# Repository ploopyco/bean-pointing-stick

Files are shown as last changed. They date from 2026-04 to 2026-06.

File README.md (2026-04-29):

# The Ploopy Bean Pointing Stick Mouse

The Ploopy Bean Pointing Stick

By some stroke of luck, you've made your way here. The Ploopy Bean. Your life will never be the same.

This repository contains all of the design and production files necessary to make a Ploopy Bean. We've also included some kick-ass documentation on how to get it made, assemble it, and program it [which you can find here](https://ploopyco.github.io/bean-pointing-stick/).

What are you waiting for? Your new life awaits.

## QMK?!

Beans bought from the [Ploopy store](https://ploopy.co/shop/bean-pointing-stick/) come with QMK preloaded. [Check out the documentation](https://ploopyco.github.io/bean-pointing-stick/) for instructions on how to load new firmware onto your device. (It's super easy!)

The firmware file that ships with all Beans is included in this repository as well, as `firmwares/bean.uf2`.

In case you are new to the world of QMK, it is an open-source firmware for computer input peripherals. You can find the source code for all of our firmwares in [QMK's Github repository](https://github.com/qmk/qmk_firmware/tree/master/keyboards/ploopyco).

Note that you may have to look for specific development branches in order to find the source for all of our firmwares, as we frequently have pending pull requests.

## Under what license is this released?

As per QMK's licensing requirements, the firmware for the Ploopy Bean Pointing Stick is released under GPLv3. Hardware design files, including electronics and mechanical files, are released under OHL CERN v2-S. Check the respective directories for full license text.

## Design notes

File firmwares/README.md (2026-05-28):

The firmware that ships on all Beans is `bean.uf2`.

## MacOS scrolling issues

Certain operating systems, like MacOS, don't play well with the high-res scrolling implementation. For more details, see: https://github.com/qmk/qmk_firmware/issues/17585#issuecomment-2325248167

This issue causes the drag scroll function to go much too fast on MacOS. The current fix is to use the `bean_no_high_res_scroll.uf2` firmware, which reduces scrolling to a usable speed.

Flashing the new firmware is easy; just hold down the bottom-left button while plugging the Bean in. Your computer should recognize a USB mass storage device was just plugged in. After that, copy and paste the firmware onto the device, and you're done.

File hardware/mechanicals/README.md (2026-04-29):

## Only one file? Where are the parts?

The STEP/STL files contain all of the plastic parts in one file. Doing it this way preserves the assembly information, showing how the parts are supposed to fit together, as well as the expected clearances between parts. It also bundles all of the parts for a given revision together, so there's no accidental mixing of parts from different revisions.

## How do I print this?

You'll need to split the parts in the file up before you can print them. Most slicers can do this; if you have a compatible printer we recommend PrusaSlic3r, since that's the one we use in-house and have checked.

Note that submitting this file to some 3rd party print services will cause confusion, as they are expecting one body instead of many. To do this, you can use PrusaSlic3r to split the parts and then export each separately as an STL.

## Why don't you include a .gcode file?

For your safety. Uploading a .gcode file onto a printer can be extremely hazardous if that .gcode file wasn't specifically generated for that printer. We don't want to come anywhere near that sort of scenario, so we are not going to upload a .gcode file.

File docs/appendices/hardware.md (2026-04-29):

# Appendix C: Hardware

## Buying hardware from us

Getting all of the hardware on your own can be tricky because the parts you select may not fit perfectly. [That's why we sell fully-assembled Beans](https://ploopy.co/product-category/bean/). Here's why that's great for you:

- Everything is guaranteed to fit together perfectly
- Everything is guaranteed to work as intended
- You'll end up saving money - probably quite a bit of money - by not spending on extra parts

Your call. You'll sort it out.

## Getting your own hardware

This guide was a bit light on detail in the other sections, and that's because the hardware has to conform to many specifications. They'll all be listed here.

First, a complete list of all the hardware you'll need:

- \#2 3/8" screw
- 6mm diameter x 2mm thick magnet
- 4x friction pads

We'll be going over all of them in detail. There will be mentions of *critical specifications*; if you're going to be sourcing your own parts, **you must get parts that conform to the critical specifications**. If you go off-menu, the parts will not fit the way that we intended when we designed the Bean. That might mean that your Bean **doesn't work**.

Let's get cracking.

### Screws

Here are the critical specifications:

- \#2
- 3/8" length

### Magnets

Here are the critical specifications:

- 6mm diameter
- 2mm thickness

### Friction pads

Here are the critical specifications:

- Any size
- Non-slip

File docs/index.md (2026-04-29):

# Home

So, you want to build a Ploopy Bean, eh? Or, maybe you want to replace some broken parts. Maybe you want to reprogram it. Or maybe you just want to know how it all works. No matter the motivation, this is the place to learn.

**Sourced the parts and itching to get it built?** --> Get started by going to the [assembly instructions](assembly-instructions.md).

**Looking to purchase your own Bean?** --> [Check out the Ploopy store](https://ploopy.co/product-category/bean).

**Building a Ploopy Bean from scratch?** --> Get started by going to [Appendix A: Printed circuit boards](appendices/pcbs.md).

---

*Copyright (C) 2026 Ploopy Corporation. Permission is granted to copy, distribute and/or modify this document under the terms of the GNU Free Documentation License, Version 1.3 or any later version published by the Free Software Foundation; with no Invariant Sections, no Front-Cover Texts, and no Back-Cover Texts. A copy of the license is included in the section entitled "GNU Free Documentation License".*

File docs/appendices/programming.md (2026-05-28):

# Appendix D: QMK Firmware Programming

## Working with QMK

Ploopy devices are fairly easy to program and reprogram, thanks to the excellent work by all of the developers and maintainers of the [QMK firmware suite](https://github.com/qmk/qmk_firmware).

## Before you begin

If you have never used QMK before, go through [all of the steps in the QMK guide to set up your environment](https://docs.qmk.fm/#/newbs_getting_started).

QMK was built for keyboards, so you'll see lots of references to code that looks like the following:

`-kb <keyboard>`

Whenever you see that, use the following syntax:

`-kb ploopyco/bean`

and you'll be fine.

## Building the Ploopy device firmware

Using QMK MSYS or your compilation toolchain of choice, compile the firmware with the following command:

`qmk compile -kb ploopyco/bean/rev1_001 -km default`

For more details on building QMK firmware in general, see the [QMK firmware guide](https://docs.qmk.fm/#/newbs_building_firmware).

## Putting the Ploopy device into bootloader mode

Under normal circumstances, the device can be put into bootloader mode with a special startup procedure.

1. Identify the "bootloader" button on the device's keymap. [The default keymap is available here](keymap.md).
2. Unplug the device.
3. Hold down the "bootloader" button.
4. Plug in the device.
5. The computer should recognise that a mass storage device was just plugged in. Once this is done, you should be able to drag and drop files onto the Ploopy device, as if the board was a USB drive.

And that's it. While plugged in this way, the Ploopy device will accept new firmware.

If you want to upload a new firmware file (a ".uf2" file, like "ploopy_aplus_v42069" or something), just drag it into the folder, and it'll automatically install on the Ploopy device and restart itself.

## Putting the Ploopy device into bootloader mode if the device is bricked

If the device cannot be put into bootloader mode using the above procedure, there is another procedure that can be used to force the device into bootloader mode. However, it involves opening the device and is more involved.

1. Unplug it from your computer.
2. Open it by removing the screws in the Base and removing the Top.
3. Look for a pair of vias (gold-plated holes) on the board. Here's a photo for reference:

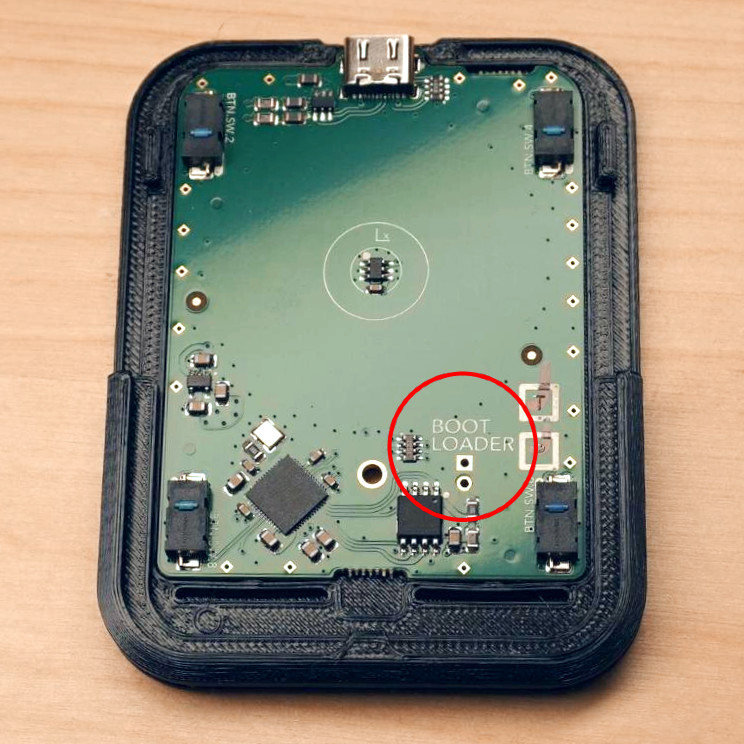
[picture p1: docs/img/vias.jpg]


4. Get a paper clip (non-insulated, i.e. no plastic covering it) or a pair of tweezers, or some wire. Whatever you've got on hand that's metal.
5. Stick the paper clip or tweezers into the holes. You're trying to form an electrical connection between the two holes.
6. While you've got the two vias connected with your metal bridge, plug the Ploopy device into your computer.
7. The computer should recognise that a mass storage device was just plugged in. Once this is done, you should be able to drag and drop files onto the Ploopy device, as if the board was a USB drive. Feel free to remove the tweezers or paperclip at this point.

And that's it. While plugged in this way, the Ploopy device will accept new firmware.

If you want to upload a new firmware file (a ".uf2" file, like "ploopy_bean_v42069" or something), just drag it into the folder, and it'll automatically install on the Ploopy device and restart itself.

Whenever you want to put new firmware onto the Ploopy device, go through these steps again.

**TIP**: If your firmware is in some kind of strange state and uploading new firmware isn't fixing it, try uploading [a flash nuke](https://learn.adafruit.com/getting-started-with-raspberry-pi-pico-circuitpython/circuitpython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) to the bean before flashing the new firmware. It wipes the memory of the bean completely clean, which can help clear a few types of errors.

## And that's it!

Happy customizing!

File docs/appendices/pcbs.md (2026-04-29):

# Appendix A: Printed circuit boards

## Buying boards from us
Getting the Ploopy boards made can be complex, and expensive, especially if you only need one set. [That's why we sell fully-assembled Beans](https://ploopy.co/product-category/Bean/). Here's why that's great for you:

- You get a PCB with all components soldered
- The firmware is already programmed on the microcontroller, so you won't have to program it
- It'll cost a hell of a lot less than if you do a production run of PCBs just for yourself
- You won't have to order components and wait while they come in
- We guarantee that it works

Just something to consider. You're smart. You'll figure it out.

## Making your own boards

Want to make your own Ploopy Bean boards? Great! Less work for us. Seriously, though, only choose this option if you know what you're doing. You don't want to embarrass yourself, do you?

### Step 1: Order the PCBs from a PCB production company

Here are the most important configurations you'll need to communicate to the company:

- 4 layers
- FR-4, TG 150-160 (basically, whatever the cheapest option is)
- 1.6mm thickness
- 6/6mil track/spacing distance
- 0.3mm minimum hole size
- ENIG surface finish, but you can go with HASL if you don't care about lead poisoning
- 1oz copper thickness for both outer and inner layers
- Choose whatever colours you want for solder mask and silkscreen; we like green solder mask and white silkscreen

If something is missing from here, it's not really important.

At some point, you'll have to upload design files to the production company. Use the [electronics source files](https://github.com/ploopyco/bean-pointing-stick/tree/main/hardware/electronics) to generate manufacturing files (you'll have to convert them from their native Altium format if you're using some other platform). That should contain everything you need to get the boards made. If the production company rejects this package, however, you'll need to address the issue yourself.

### Step 2: Order the electronics components

All of the components are described in the schematics of the PCBs. Ordering the components is left as an exercise for the reader.

A complete list of all of the components can be found in the electrical design files.

### Step 3: Get the necessary tools

- PCB
- All of the electronics components
- A hot air rework tool
- Solder paste
- A printout of the schematics

### Step 4: Solder the components to the boards

Once you've got the PCBs and all of the components, print out the schematics. Use the schematics to match the reference designators on the PCBs to the reference designators on the schematics, and then get to soldering.

If you've never soldered surface mount components before, or want a refresher on how to solder, we recommend [this video on using an iron to solder surface mount components](https://www.youtube.com/watch?v=3NN7UGWYmBY), and [this video on using a hot-air soldering station](https://www.youtube.com/watch?v=c_Qt5CtUlqY).

### Step 5: All done!

Congrats, you finished assembling the electronics! Pat yourself on the back.

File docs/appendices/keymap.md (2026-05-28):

# Appendix E: Default Keymap

The default keymap for the Bean is as follows.

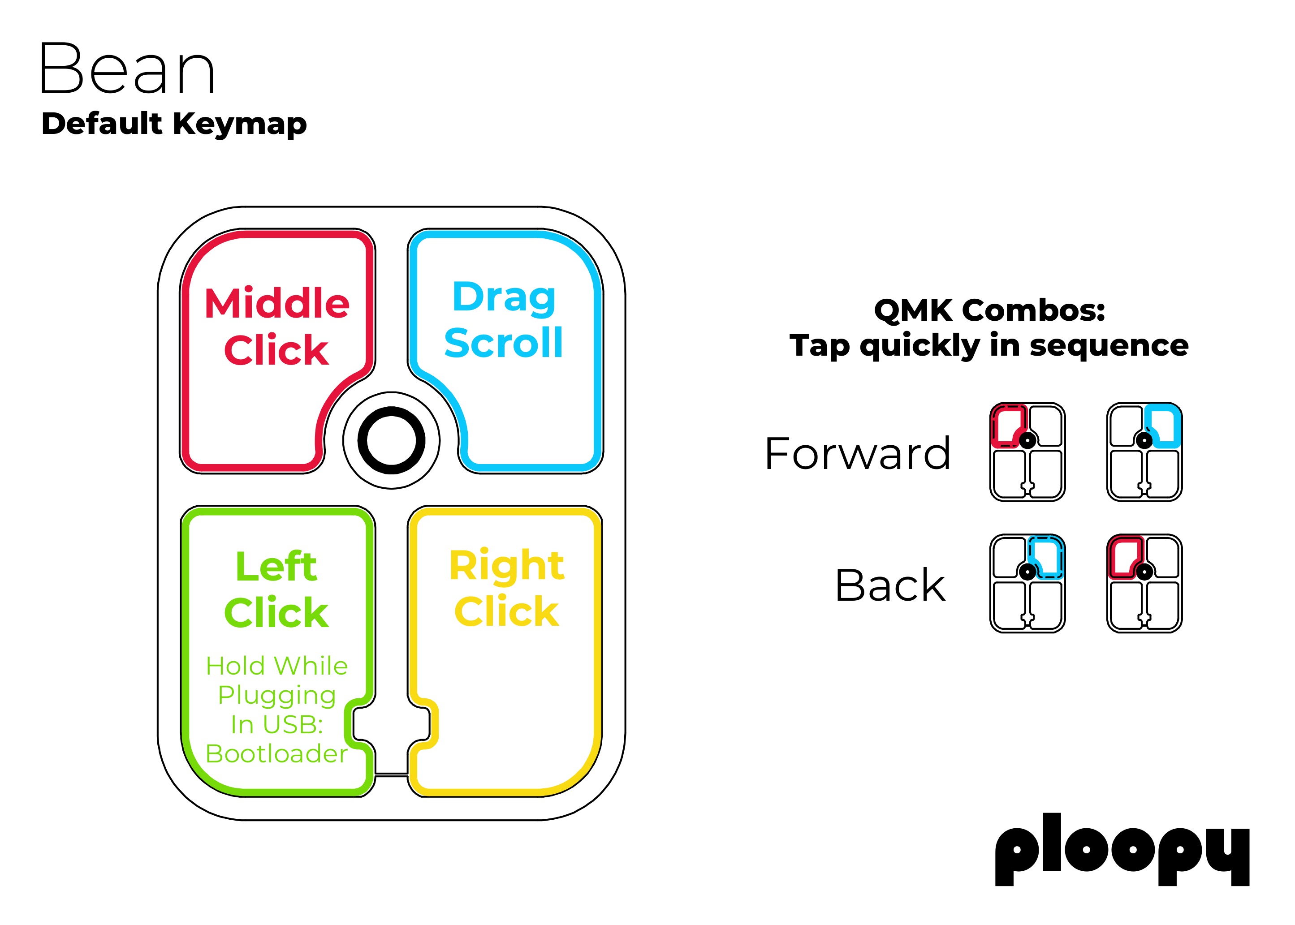
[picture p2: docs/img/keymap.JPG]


All of these functions can be customized using [VIA, a free open-source webapp](https://usevia.app).

Note that your browser needs to support WebHID in order to use VIA.

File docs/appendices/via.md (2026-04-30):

# Appendix F: Using VIA

The Bean's can be customized using a web application called "VIA". Currently, a bit of additional work is necessary to get VIA to work, but it should only take about thirty seconds.

Begin by copying and pasting the following into a text file, saving it as *bean.json*:

    {
      "name": "Ploopy Bean Pointing Stick",
      "vendorId": "0x5043",
      "productId": "0x81DC",
      "matrix": {
        "rows": 1,
        "cols": 4
      },
      "customKeycodes": [
        {
          "name": "DPI Config",
          "title": "DPI Config",
          "shortName": "DPI"
        },
        {
          "name": "Drag Scroll",
          "title": "Drag Scroll",
          "shortName": "DragScl"
        }
      ],
      "layouts": {
        "keymap": [
          [
            {
              "w": 2,
              "h": 2
            },
            "0,1",
            {
              "x": 0.25,
              "w": 2,
              "h": 2
            },
            "0,2"
          ],
          [
            {
              "y": 1.25,
              "w": 2,
              "h": 2
            },
            "0,0",
            {
              "x": 0.25,
              "w": 2,
              "h": 2
            },
            "0,3"
          ]
        ]
      }
    }

- Next, navigate to [the VIA web app](https://usevia.app), using **Microsoft Edge, Chrome, or Opera**. Any other browser that supports WebHID will work, too.
- Look at the top toolbar of the web application, and click the tab called *DESIGN*.
- Uncheck *Use V2 definitions (deprecated)*.
- Click *Load* and upload the *bean.json* file that you saved on your computer.
- Plug in the Bean if it wasn't plugged in already.
- Look at the top toolbar of the web application, and click the tab called *CONFIGURE*.
- Click *Authorize Device*. A modal window should pop up, and you should see the *Ploopy Bean* as an option to connect. Do so now.

You should now see a representation of the buttons of the Bean in the web app. You are now free to modify the button's functionality.

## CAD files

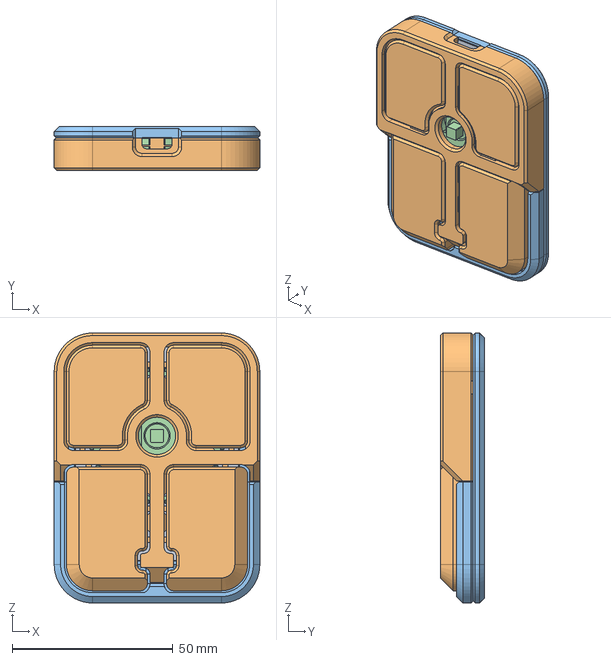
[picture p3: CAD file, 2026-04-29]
hardware/mechanicals/Bean-RevO-NoLogo.STEP
64.0 x 13.8 x 84.0 mm

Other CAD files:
hardware/mechanicals/Bean-RevO-NoLogo.STL

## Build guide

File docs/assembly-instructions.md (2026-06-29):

<style>
  .tooltip {
    padding: 15px;
    border-radius: 5px;
    margin-bottom: 10px;
    display: flex;
    align-items: center;
  }

  .tooltip .icon {
    font-size: 1rem;
    margin-right: 10px;
  }

  .tip {
    background-color: #fcf003;
    color: #333;
  }

  .warning {
    background-color: #ffb3b3;
    color: #333;
  }

  .info {
    background-color: #cce5ff;
    color: #004085;
  }

  .info a {
    color: #004085;
    font-weight: bold;
    text-decoration: underline;
  }
</style>

## Step 1: Prepare necessary tools

- A #1 Phillips head screwdriver

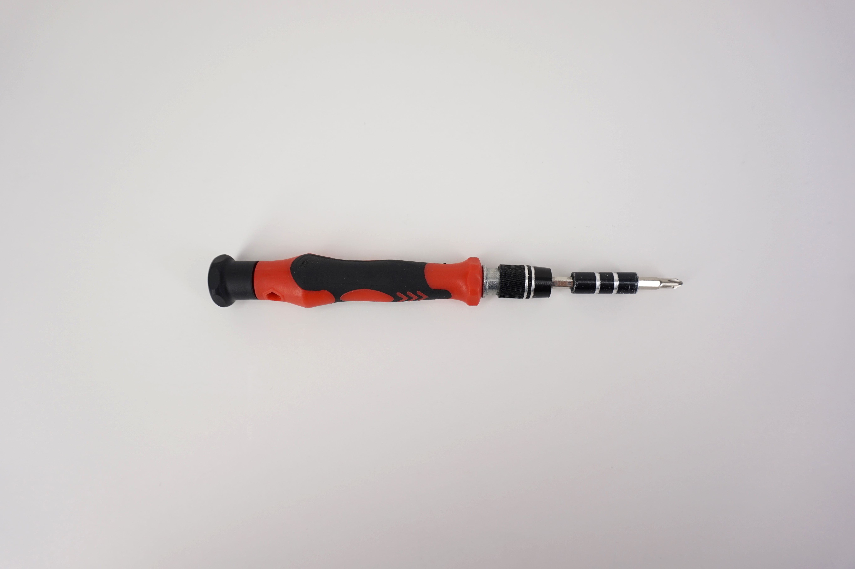
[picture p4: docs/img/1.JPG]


## Step 2: Place PCB into Base

<div class="tooltip tip">
  <span class="icon">💡</span>
  <span><strong>Tip:</strong> The PCB may require a bit of force to get in.</span>
</div>

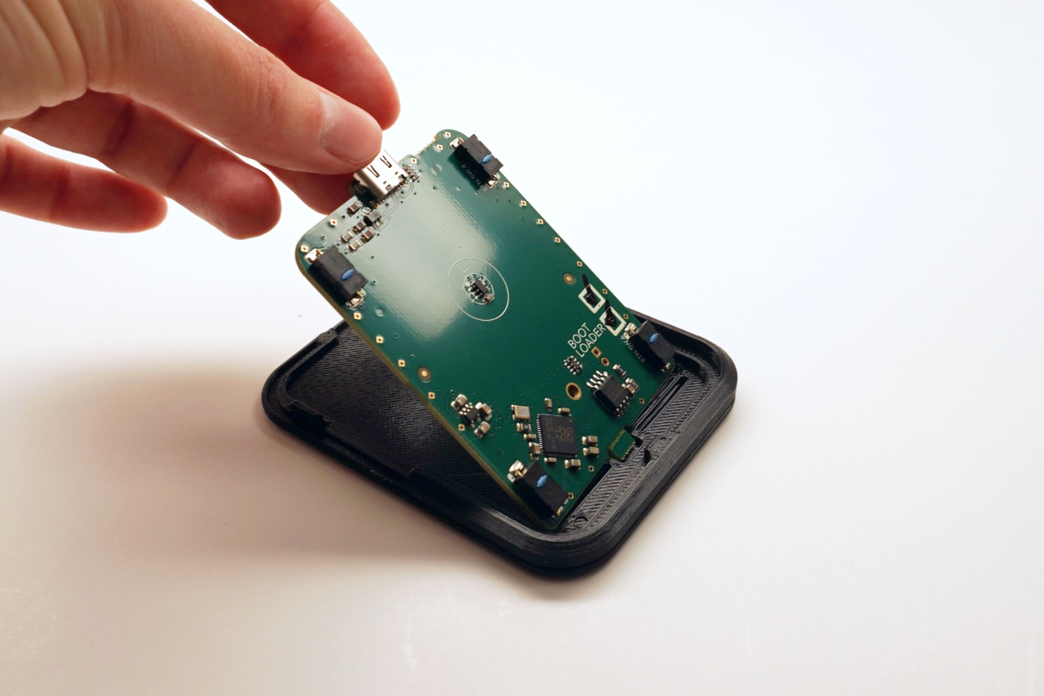
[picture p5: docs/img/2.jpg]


## Step 3: Insert Magnet into Spring

<div class="tooltip tip">
  <span class="icon">💡</span>
  <span><strong>Tip:</strong> The magnet must be inserted with the <b>north</b> side facing <b>upwards</b>. Use a compass to determine the orientation of the magnet.</span>
</div>

- The magnet requires a bit of force to fully insert.
- Once inserted, the Magnet will be very difficult to remove.

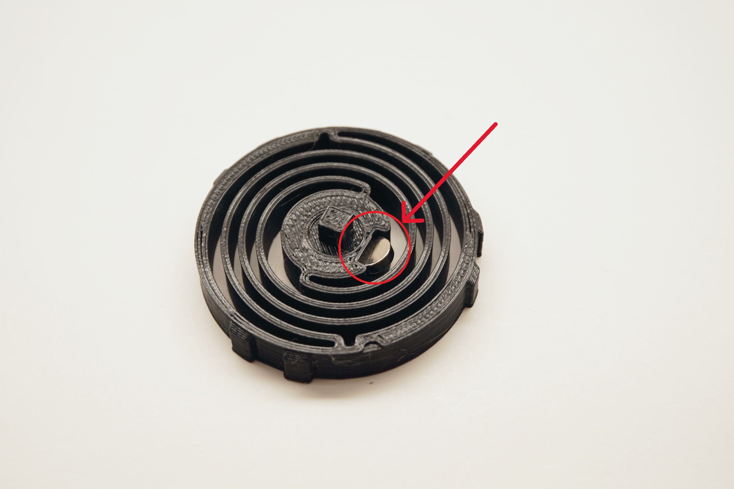
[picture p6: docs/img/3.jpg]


## Step 4: Place Friction Nub onto Spring

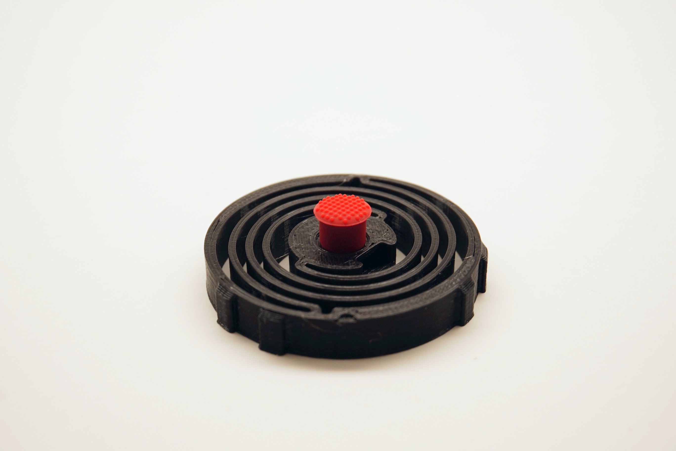
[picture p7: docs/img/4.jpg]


## Step 5: Place Spring into Top

<div class="tooltip tip">
  <span class="icon">💡</span>
  <span><strong>Tip:</strong> The Spring must be oriented correctly in order to properly insert. See the photo for details.</span>
</div>

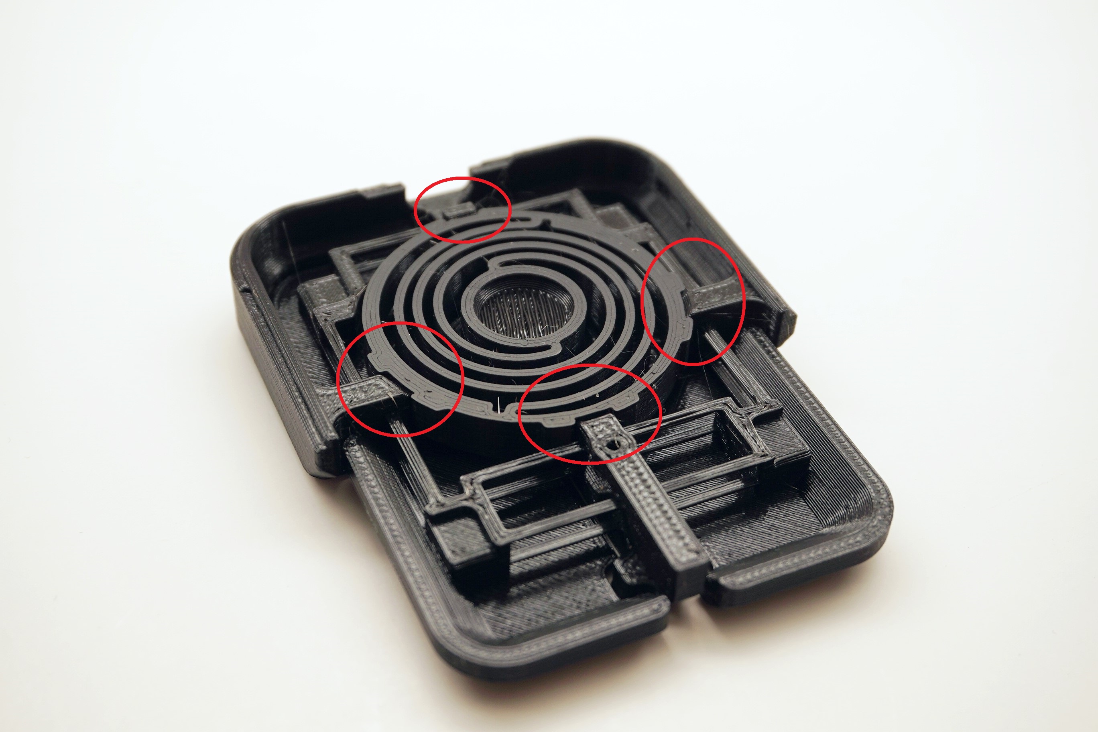
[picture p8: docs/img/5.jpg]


## Step 6: Place Top onto Base

<div class="tooltip tip">
  <span class="icon">💡</span>
  <span><strong>Tip:</strong> The Top should snap into place on the Base.</span>
</div>

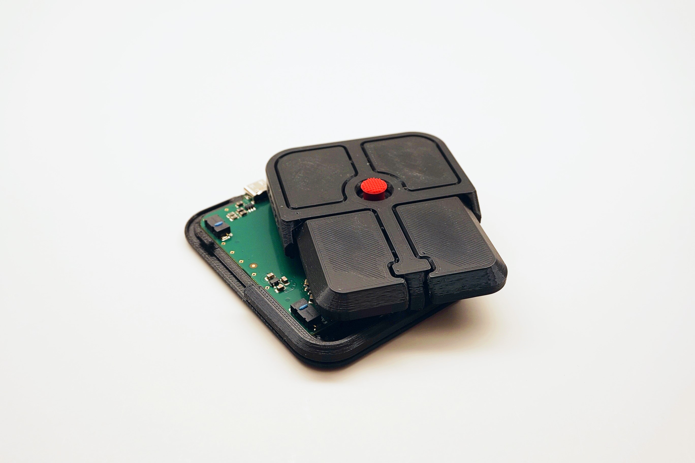
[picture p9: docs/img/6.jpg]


## Step 7: Screw Top to Base

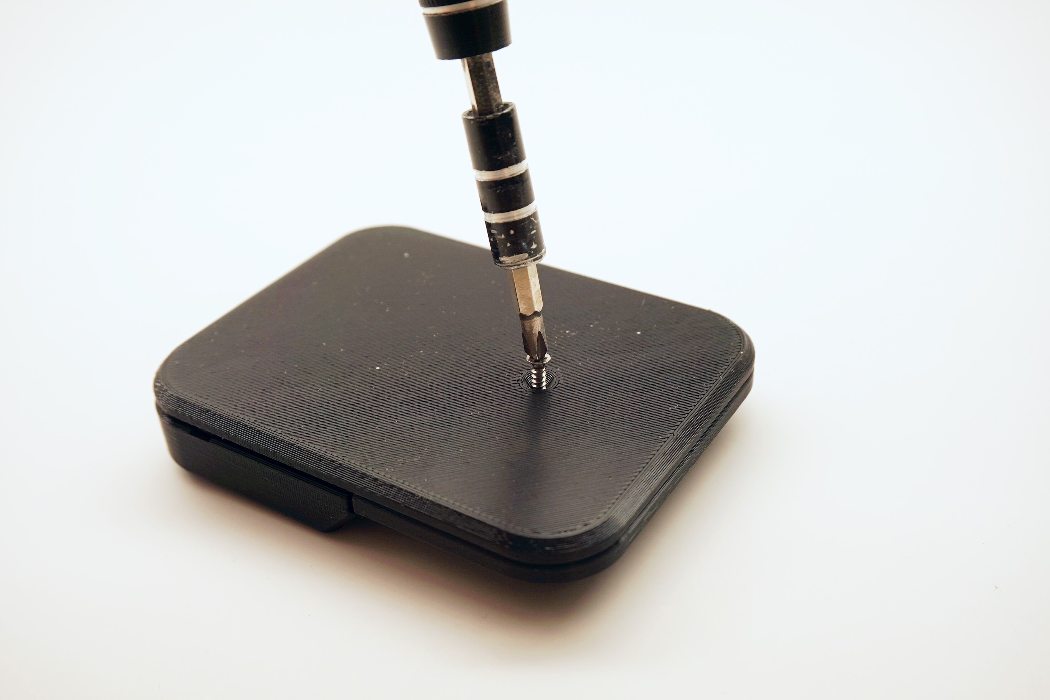
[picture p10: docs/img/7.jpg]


## Step 8: Place Friction Pads on Base

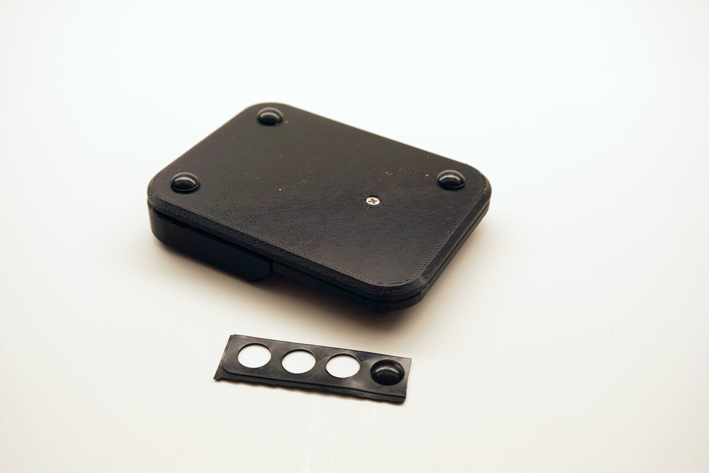
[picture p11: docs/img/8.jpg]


## Step 9: All done!

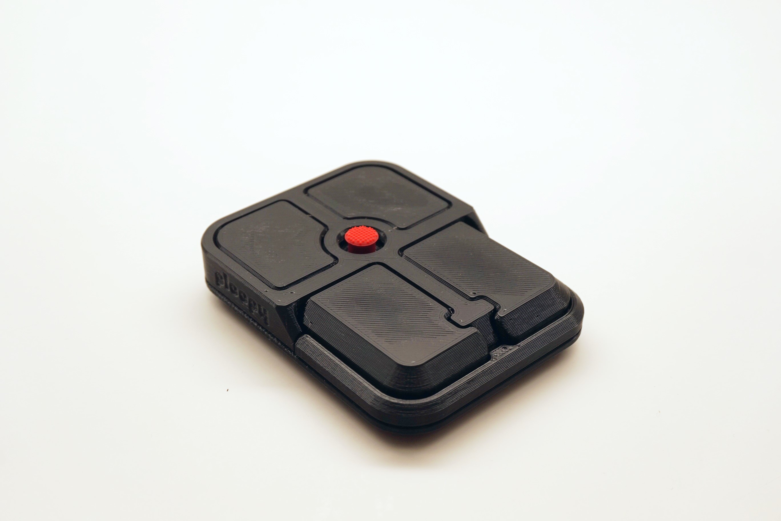
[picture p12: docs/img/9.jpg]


## Post Build Steps:

### Verify the device is working correctly

- Plug the Bean into the computer using a USB-C cable
- Move the nub around, it should move the cursor
- Press each of the buttons to verify their function

<div class="tooltip info">
  <span class="icon">ℹ️</span>
  <span><strong>Info:</strong> The default keymap for the Bean is <a href="../appendices/keymap/">here</a>.</span>
</div>

### Check out Post Build FAQ
- [Post Build FAQ](https://help.ploopy.co/?docs=where-can-i-find-mods-for-my-ploopy-device)
- Contains various information about things you can do after initial assembly!

<div class="tooltip info">
  <span class="icon">ℹ️</span>
  <span><strong>Info:</strong> If the device is not working, consult our <a href="https://help.ploopy.co/checklist-v2/">troubleshooting guide</a> for further steps.
</div>

<!--
<div class="tooltip tip">
  <span class="icon">💡</span>
  <span><strong>Tip:</strong> Here's an interesting piece of info!</span>
</div>

<div class="tooltip warning">
  <span class="icon">🚨</span>
  <span><strong>Warning:</strong> Here's a warning!</span>
</div>

<div class="tooltip info">
  <span class="icon">ℹ️</span>
  <span><strong>Info:</strong> Here's some cool stuff!</span>
</div>
-->

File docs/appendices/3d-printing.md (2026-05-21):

# Appendix B: 3D printed parts

## Buying 3D-printed parts from us
Not everyone has access to a 3D-printer. [That's why we sell fully-assembled Beans](https://ploopy.co/product-category/bean/). Here's why that's great for you:

- You get all of the 3D-printed parts, guaranteed free of manufacturing defects
- You won't waste time spending hours tweaking settings
- We guarantee it will fit together *perfectly*

Consider it. You're a smartie. You'll get there.

## Printing your own parts

So, you have a printer and want to print your own parts? Great! We don't have specific instructions, since every printer setup is different. All of the STLs are available, and if you need to make tweaks, you can alter the design files.

Here are the settings we use when we print parts. **Note that these settings have only been tested on the Prusa i3 MK2.5S and MK3S.** If you have another printer, you may need to tweak these settings.

- PLA. The geometry of many of the parts is quite complex; trying to use other materials may not result in success.
- 0.20mm layer height. You can go finer than this if you want, but we haven't tested that. Going coarser is not going to work; first, it's going to feel rough on your hand, and second, it won't accurately capture the necessary detail.
- No support material is necessary. If your slicer is showing support material, you didn't orient the parts correctly.
- Orient the pieces so that flat sides are on the build plate.
- We like gyroid for infill pattern, but anything is probably good. Cubic, rectilinear, whatever.
- We use 0.4mm nozzles. We haven't tested other nozzle sizes.

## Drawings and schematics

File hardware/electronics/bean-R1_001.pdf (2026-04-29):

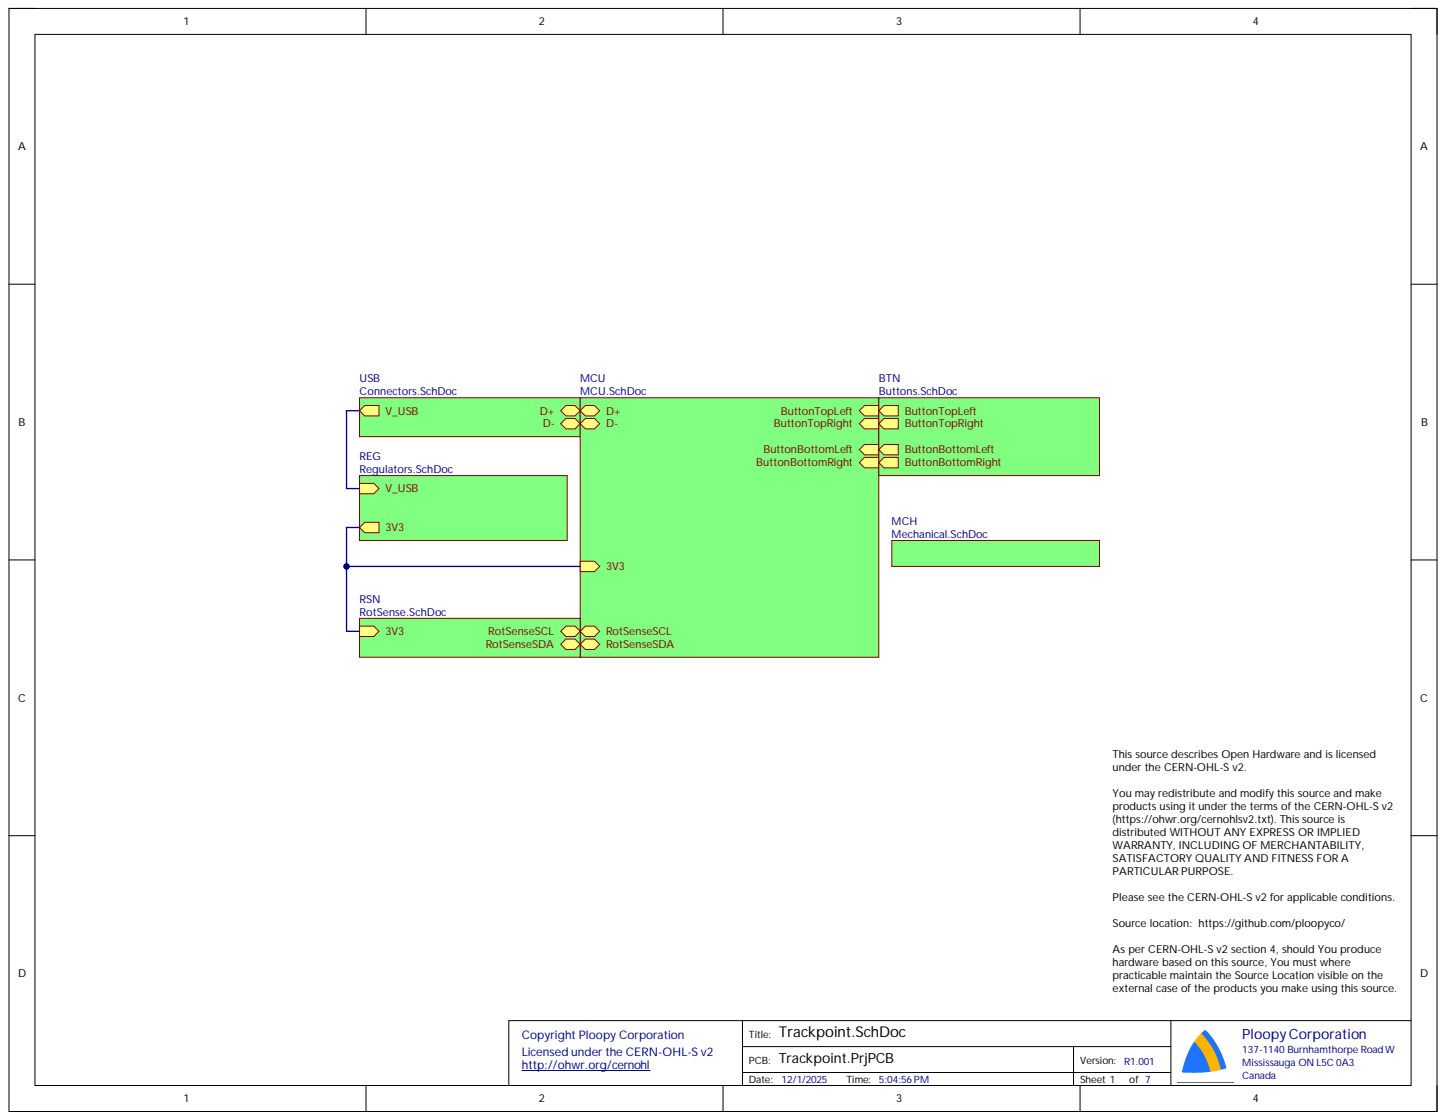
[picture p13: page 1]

This source describes Open Hardware and is licensed
under the CERN-OHL-S v2.

You may redistribute and modify this source and make
products using it under the terms of the CERN-OHL-S v2
(https://ohwr.org/cernohlsv2.txt). This source is
distributed WITHOUT ANY EXPRESS OR IMPLIED
WARRANTY, INCLUDING OF MERCHANTABILITY,
SATISFACTORY QUALITY AND FITNESS FOR A
PARTICULAR PURPOSE.

Please see the CERN-OHL-S v2 for applicable conditions.

Source location: https://github.com/ploopyco/

As per CERN-OHL-S v2 section 4, should You produce
hardware based on this source, You must where
practicable maintain the Source Location visible on the
external case of the products you make using this source.

Copyright Ploopy Corporation
Licensed under the CERN-OHL-S v2
http://ohwr.org/cernohl

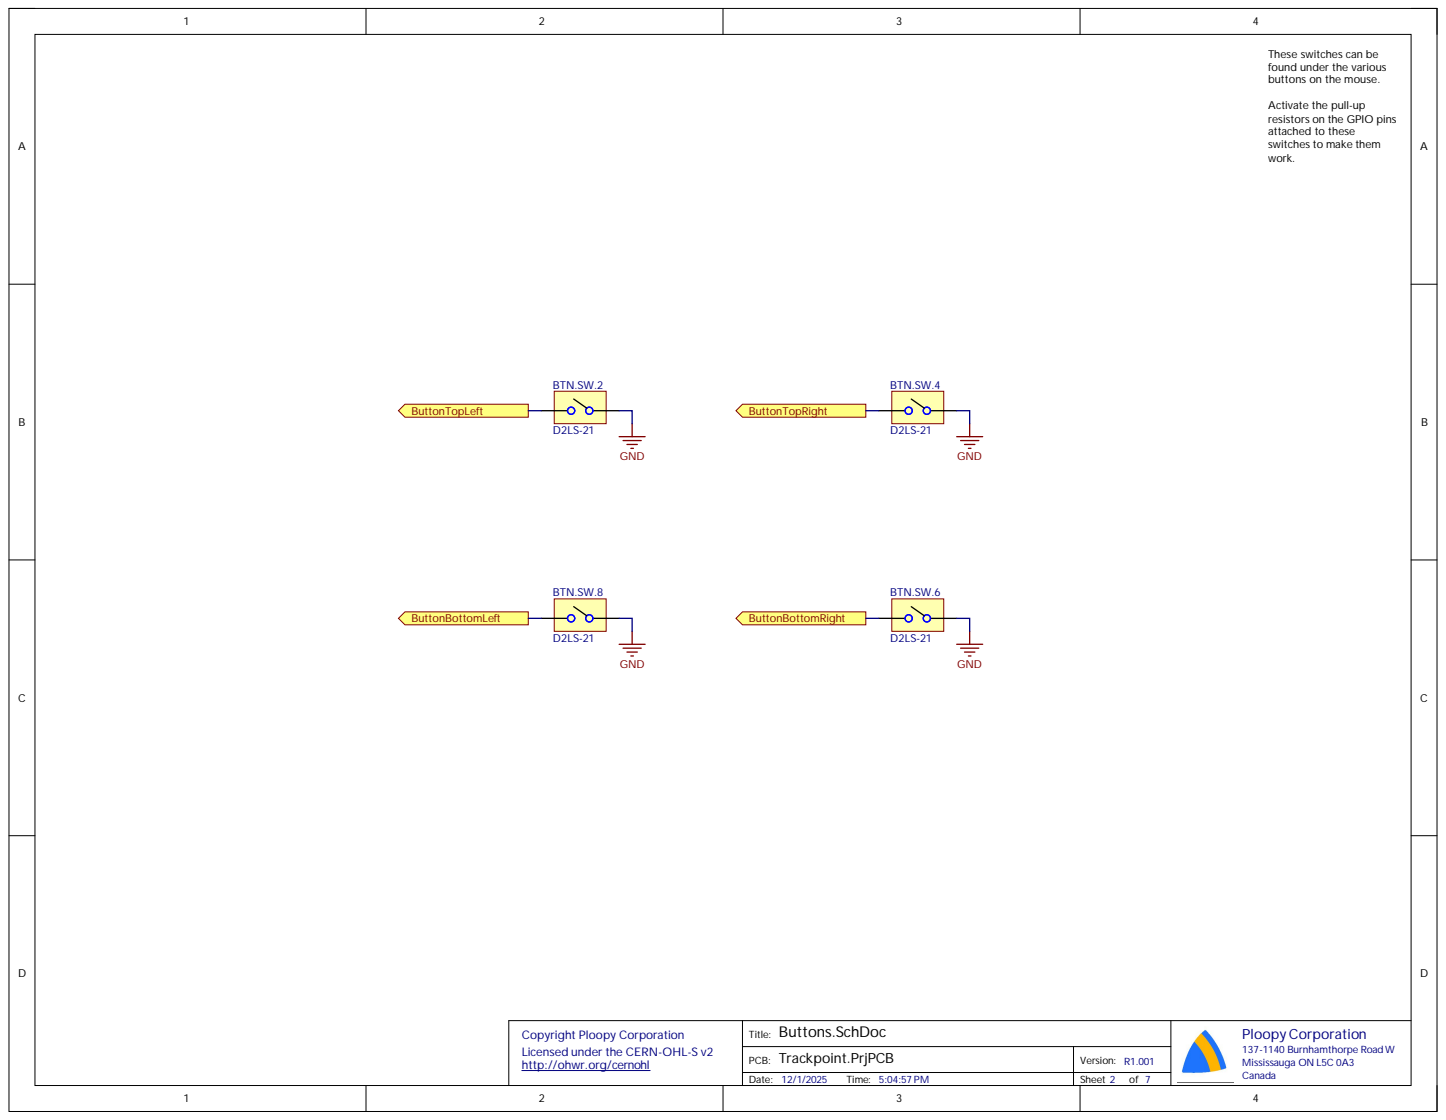
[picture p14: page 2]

These switches can be
found under the various
buttons on the mouse.

Activate the pull-up
resistors on the GPIO pins
attached to these
switches to make them
work.

Copyright Ploopy Corporation
Licensed under the CERN-OHL-S v2
http://ohwr.org/cernohl

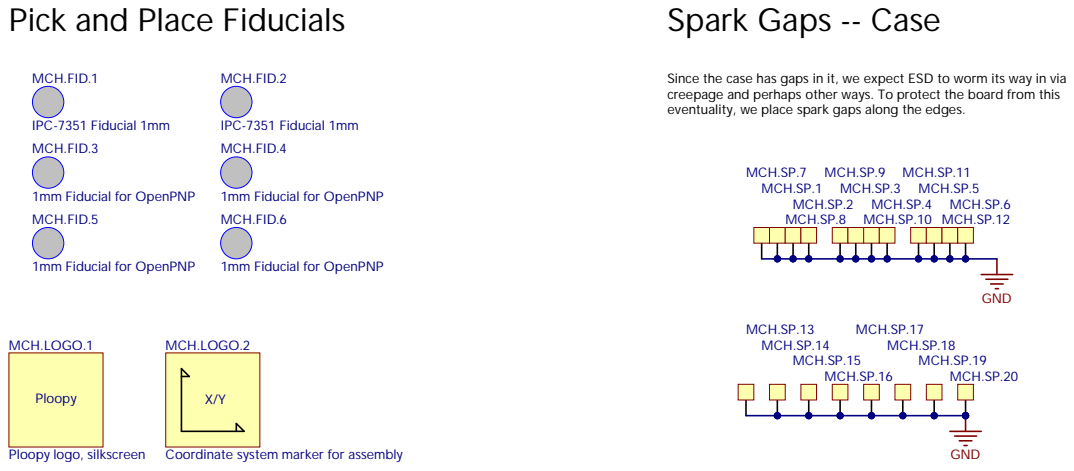
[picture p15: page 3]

Pick and Place Fiducials

Spark Gaps -- Case MCH.SP.7 MCH.SP.1 MCH.SP.8 MCH.SP.2 MCH.SP.9 MCH.SP.3 MCH.SP.10 MCH.SP.4 MCH.SP.1

Since the case has gap
creepage and perhap
eventuality, we place spark gap

s other ways. To protect the board from this

pect ESD to worm its way in via

Coordinate system marker for assem

Cop
Licensed under the CE
http

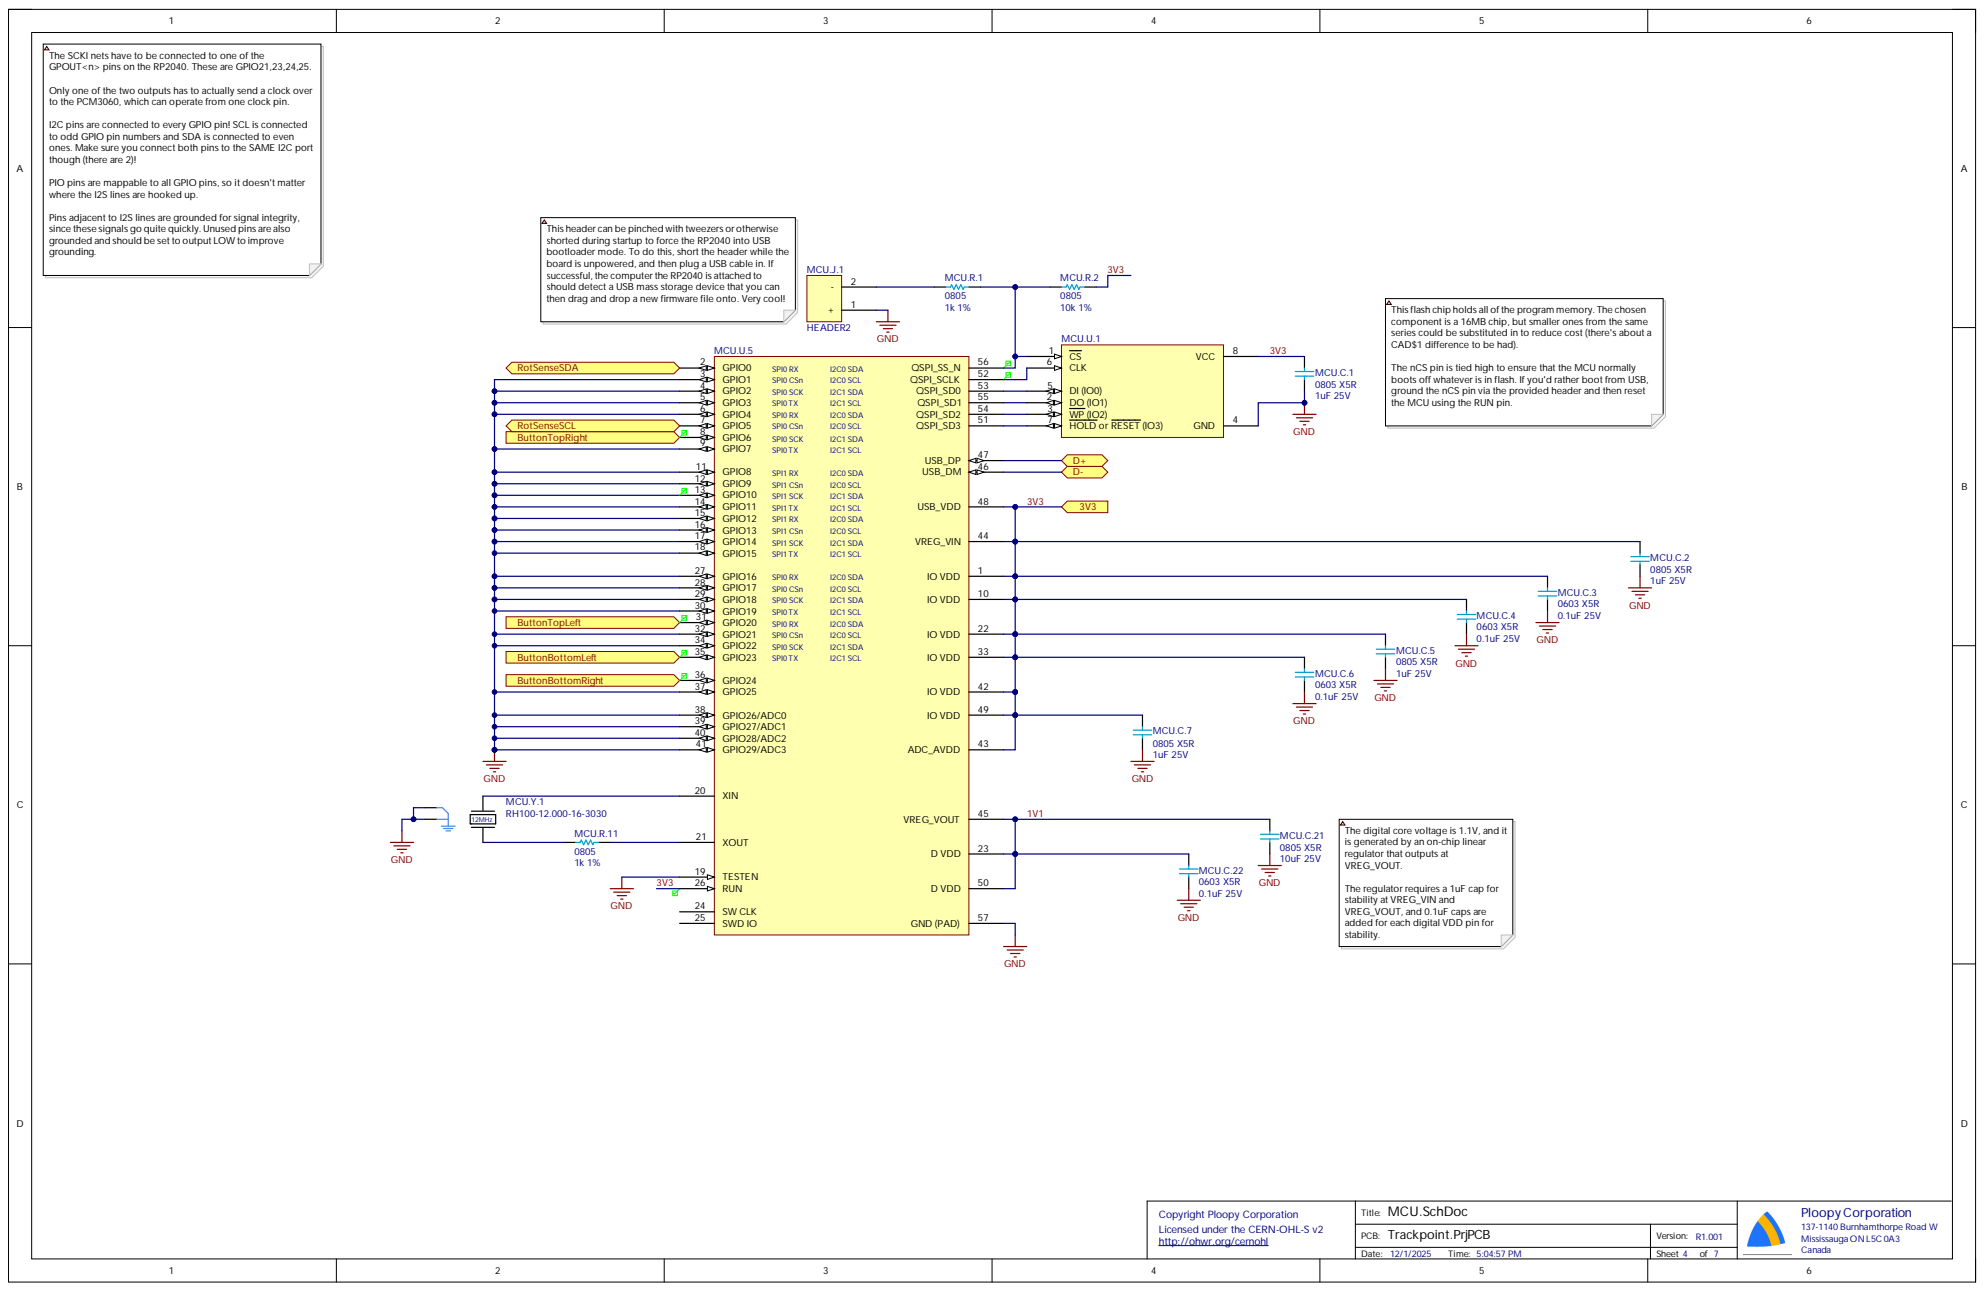
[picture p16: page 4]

The SCKI nets have

R o tSenseSC L 7 ButtonT o p R i g ht | | 7

Cop y rig h t Ploop y Corpora tion Lice nsed u n d e r th e CE R N -OH L -S v 2 h ttp : //ohwr .org /ce rnoh l | T i tl e: MC U.Sc h Doc | Plo opy C o rpo ra ti o n 1 37-1 1 40 B u rn h a m thorp e Roa d W M i ssi ssa u g a O N L 5C 0A 3 C a n ad a

PC B : Trackpoin t.P rj PC B | Ve rsion : R 1 . 001

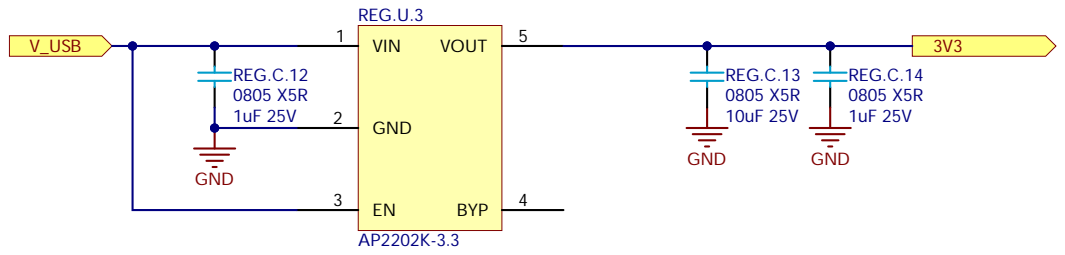
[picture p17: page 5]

Copyright Ploopy Corporation
Licensed under the CERN-OHL-S v2
http://ohwr.org/cernohl

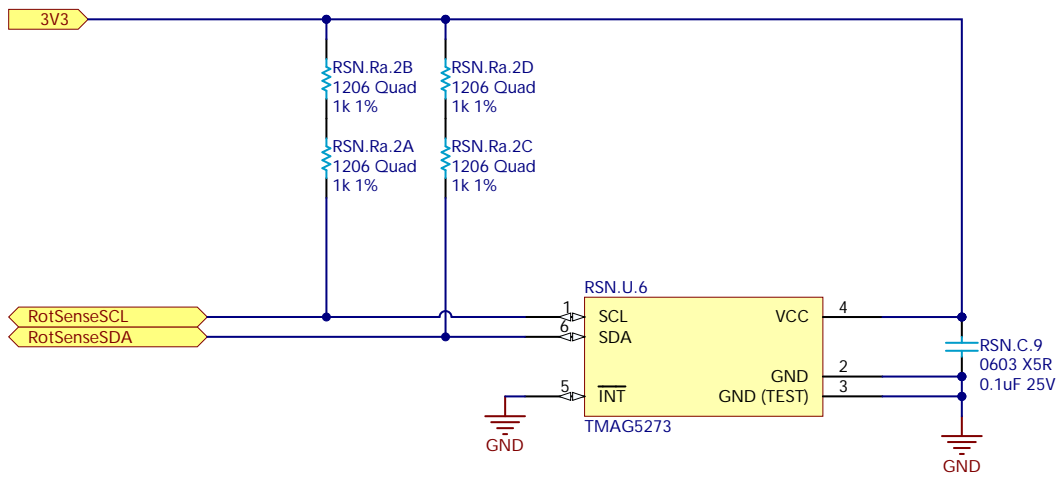
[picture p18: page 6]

Cop
Licensed under the CE
http

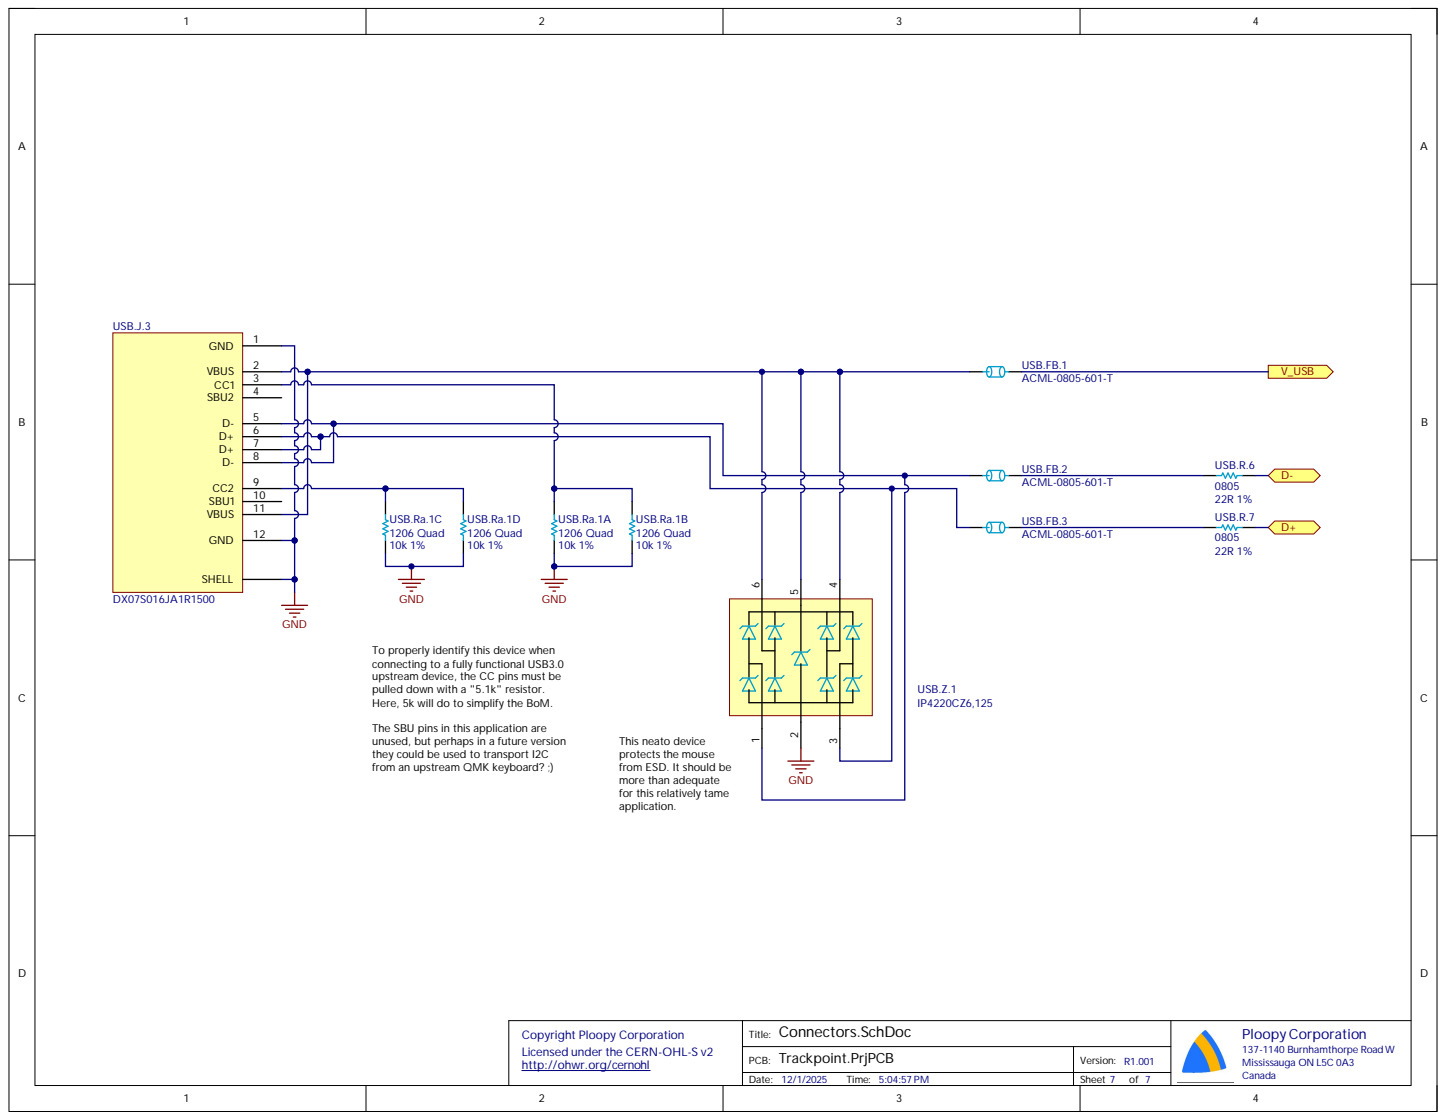
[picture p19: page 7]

To properly identify this device when
connecting to a fully functional USB3.0
pulled down with a "5.1k" resistor.
Here, 5k will do to sim

The SB
unused, but perhap
they could be used to transport I2C
from an up

U pins in this ap

This neato device protects the mouse

from ESD. It should be more than adequate

for this relatively tame

Cop
Licensed under the CE
http

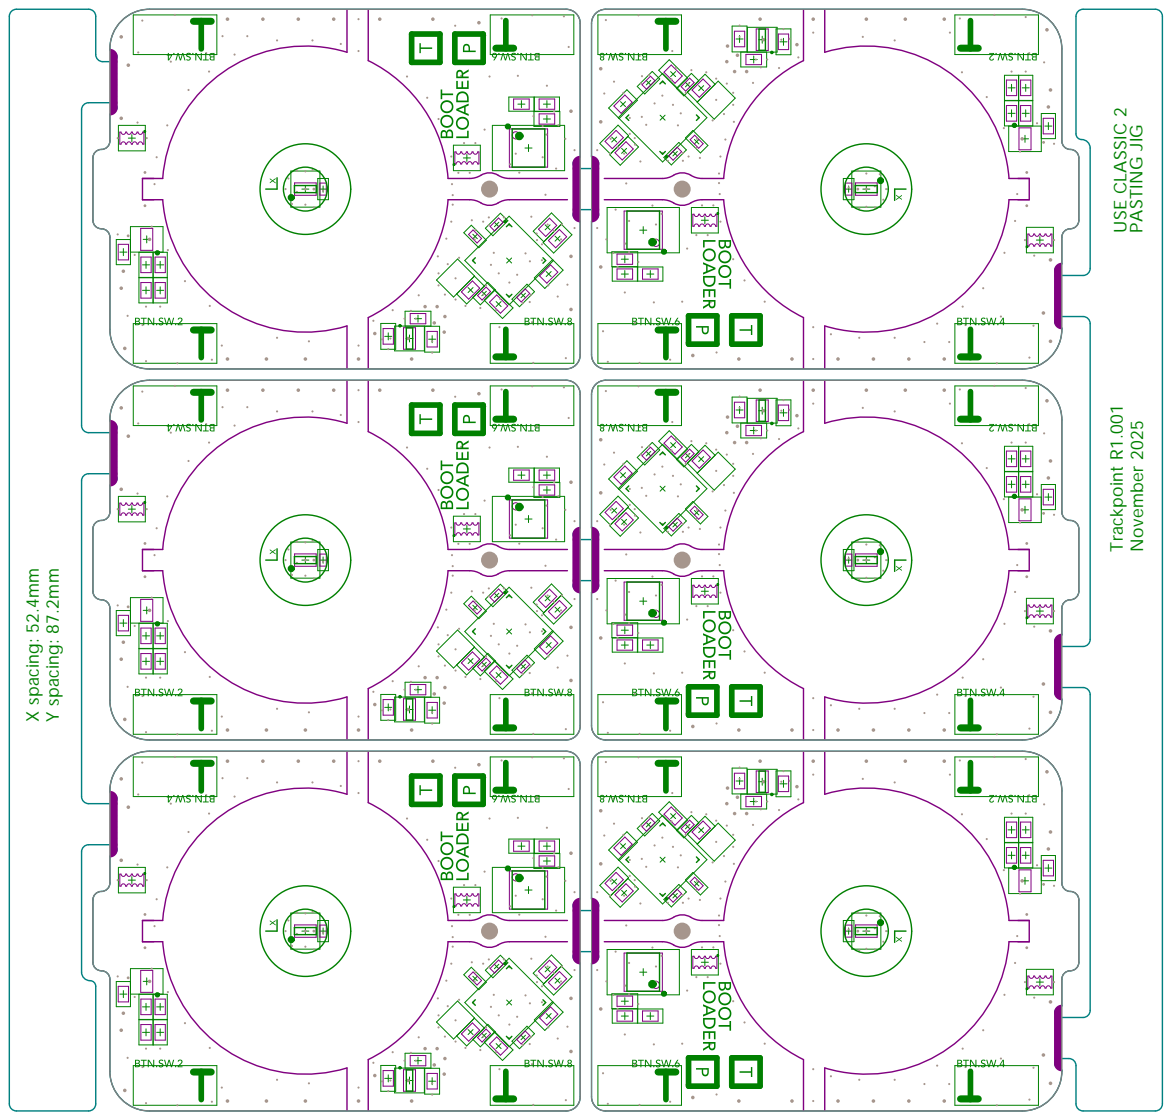
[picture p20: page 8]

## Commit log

2026-04-29 initial release
    [Bean-RevO-NoLogo.STEP, Bean-RevO-NoLogo.STL, Buttons.SchDoc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]
2026-06-29 Update assembly-instructions.md
    Removed link to broken part
